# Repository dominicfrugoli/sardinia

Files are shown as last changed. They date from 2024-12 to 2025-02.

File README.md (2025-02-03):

<br/>
<div align="center">

<h3 align="center">Sardinia</h3>
<p align="center">
Sampler based on the Electrosmith Daisy platform

</p>
</div>

## About The Project

[Notion Project Homepage](https://fenidesign.notion.site/Sardinia-Independent-Project-24255e64caba44d3b6232d27743844be?pvs=4)

Sardinia is the codename for a sampler that is currently being built by me for an Independent Project during my senior year at Columbia College Chicago. It uses the Electrosmith Daisy platform and is an exercise for me to venture into the world of product design.

This independent project is called "The Product Design Process for Electronic Instruments" and was pitched by myself specifically to give myself experience in the process of the full production of an audio hardware device. This means starting at research, then going through every stage of production and design to end up with a final product. There is a large emphasis on the process and showing future companies that I understand somewhat what it takes.
### Built With

- [Daisy Seed](https://electro-smith.com/products/daisy-seed)
- [libDaisy](https://github.com/electro-smith/libDaisy)
- [DaisySP](https://github.com/electro-smith/DaisySP)
- [KiCad](https://www.kicad.org/)
- [Fusion 360](https://www.autodesk.com/products/fusion-360/)
## Roadmap

##### Weeks 1-5 | Ideation and Programming

- Week 1
    - Come up with overall idea and mission statement for the instrument
    - Research DSP ideas and programming concepts needed
    - Gather ideas and inspiration from specific hardware
- Week 2 & 3
    - Start programming all DSP and hardware handling for instrument
    - Lots of iteration and testing will be needed
    - Research here is critical as well to get main audio concepts down
    - Daisy Examples will be main research source
    - Recording different iterations of the project will be great for documentation
- Week 4 & 5
    - Work on finalizing code and getting it to a point for implementation
    - Use daisy examples and others’ code to help with style guidance
    - Get friends to test out for playability and sound, as well as get ideas
    - Build a central repo for code which can be updated as needed
    - Coding doesn’t stop with this step, but it should be mostly done by now
    - Start recording breadboard schematics if time allows to make PCB design easier

#####  Weeks 6-10 | PCB and Hardware Design

- Week 6 & 7
    - Refresh KICAD skills with tutorials
    - Build out schematic for PCB in KICAD
    - Design PCB completely and order for testing in week 8 & 9
    - Case design will be important here to make sure layout works with PCB
    - Final component selection will take place here
- Week 8 & 9
    - Work on case design with cardboard PCB to test out everything
    - Decide on case material (likely 3D printed)
    - Build out specifics for case such as standoff points and strength areas
    - Allow case to have daisy in a place that is easily reprogrammed
    - Assemble and test PCBs once they arrive (make changes and reorder if necessary)
    - Finish working on design and model for case
- Week 10
    - Start putting together first prototype of instrument with printed PCB and case
    - Play with instrument musically and have others try
    - This is when a lot of testing can be done for the usability

#####  Weeks 11-15 | Manufacturing and Documentation

- Week 11
    - Finalize design of case and overall visual style of instrument
    - Work on process for assembling, as well as BOM and any other assembly materials
- Week 12 & 13
    - Work on customer documentation for instrument
    - Design manual for the user
    - Design packaging for the instrument
    - Work on advertising and marketing for it
- Week 14 & 15
    - Build final version of instrument to be shown and displayed
        - Maybe one fully complete and two hollow cases for ad campaign
    - Final write up and documentation for instrument
    - Add writeup to portfolio website
    - Present it to friends and professors
    - Any last requirements for Visda

## Contact

Dominic Frugoli - [Portfolio](https://www.dominicfrugoli.com/) - dominicfrugoli@gmail.com

Project Link: [Notion Page](https://fenidesign.notion.site/Sardinia-Independent-Project-24255e64caba44d3b6232d27743844be?pvs=4)
## Acknowledgments

- Dr. Visda Goudarzi

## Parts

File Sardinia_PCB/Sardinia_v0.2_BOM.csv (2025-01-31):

Id | Designator | Footprint | Quantity | Designation | Supplier and ref
1 | R10,R24,R22,R31,R1,R17,R27,R21,R12,R19,R14,R3,R25,R9,R11,R7,R6,R18,R8,R26,R13,R30,R29,R15,R32,R23,R4,R16,R2,R5,R28,R20 | R_1206_3216Metric_Pad1.30x1.75mm_HandSolder | 32 | 10K
2 | RV3,RV1,RV6,RV5,RV4,RV2 | Potentiometer_Alpha_RD901F-40-00D_Single_Vertical | 6 | B10K
3 | SW34 | SW_Cherry_MX_1.00u_PCB | 1 | ControlButton_2
4 | SW14,SW10,SW3,SW30,SW24,SW16,SW5,SW1,SW9,SW23,SW31,SW32,SW26,SW15,SW17,SW13,SW7,SW19,SW22,SW20,SW28,SW25,SW18,SW4,SW29,SW27,SW8,SW12,SW2,SW21,SW6,SW11 | PG1350 | 32 | SW_Push
5 | RVT1 | Potentiometer_Runtron_RM-065_Vertical | 1 | B10K_Trim
6 | SW35 | SW_Cherry_MX_1.00u_PCB | 1 | ControlButton_3
7 | D1 | D_DO-41_SOD81_P7.62mm_Horizontal | 1 | 1N5817
8 | SW39 | SW_Cherry_MX_1.00u_PCB | 1 | ControlButton_7
9 | ENC1 | RotaryEncoder_Alps_EC11E-Switch_Vertical_H20mm | 1 | RotaryEncoder
10 | SW40 | SW_Cherry_MX_1.00u_PCB | 1 | ControlButton_8
11 | DS1 | WC1602A | 1 | LCD
12 | SW33 | SW_Cherry_MX_1.00u_PCB | 1 | ControlButton_1
13 | SW37 | SW_Cherry_MX_1.00u_PCB | 1 | ControlButton_5
14 | SW38 | SW_Cherry_MX_1.00u_PCB | 1 | ControlButton_6
15 | SW36 | SW_Cherry_MX_1.00u_PCB | 1 | ControlButton_4
16 | J3 | BarrelJack_Horizontal | 1 | DC Jack
17 | J2 | Jack_6.35mm_Neutrik_NMJ6HCD2_Horizontal | 1 | OutputJack
18 | J1 | Jack_6.35mm_Neutrik_NMJ6HCD2_Horizontal | 1 | InputJack
19 | C1 | CP_Radial_D5.0mm_P2.50mm | 1 | 10uF
20 | SW41 | JST_PH_B3B-PH-K_1x03_P2.00mm_Vertical | 1 | SW_SPDT
21 | U5,U4,U3,U2,U1 | DIP-16_W7.62mm_LongPads | 5 | 4051
22 | A1 | Electrosmith_Daisy_Seed | 1 | Electrosmith_Daisy_Seed_Rev4

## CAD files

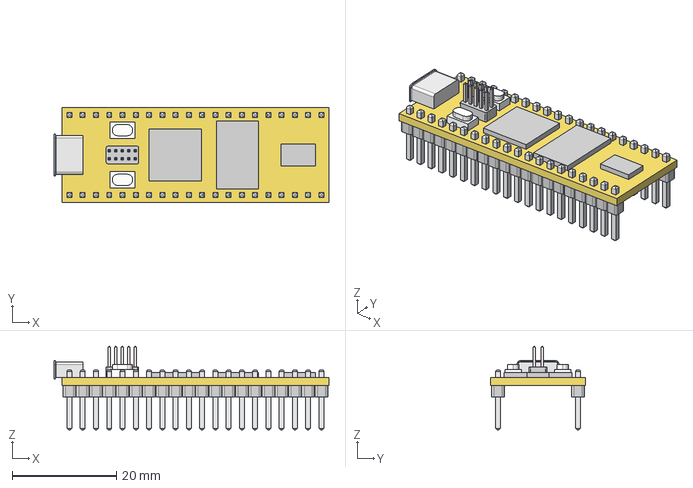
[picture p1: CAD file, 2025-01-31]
Sardinia_PCB/3Dmodels/Daisy Seed.step
52.7 x 18.1 x 16.0 mm

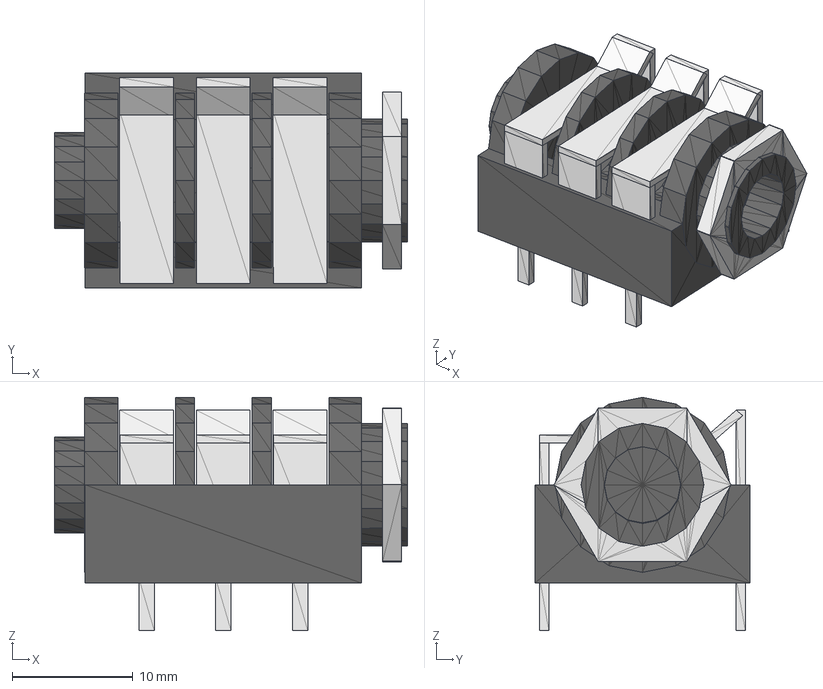
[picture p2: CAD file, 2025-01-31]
Sardinia_PCB/3Dmodels/NEUTRIKJKST.stp
29.2 x 17.8 x 19.3 mm
NEUTRIKJKST_2
NEUTRIKJKST_3
NEUTRIKJKST_4
NEUTRIKJKST_5
NEUTRIKJKST_6
NEUTRIKJKST_7
NEUTRIKJKST_8
NEUTRIKJKST_9
NEUTRIKJKST_10
NEUTRIKJKST_11
NEUTRIKJKST_12
NEUTRIKJKST_13
NEUTRIKJKST_14
NEUTRIKJKST_15
NEUTRIKJKST_16
NEUTRIKJKST_17
NEUTRIKJKST_18
NEUTRIKJKST_19
NEUTRIKJKST_20
NEUTRIKJKST_21
NEUTRIKJKST_22
NEUTRIKJKST_23
NEUTRIKJKST_24
NEUTRIKJKST_25
NEUTRIKJKST_26
NEUTRIKJKST_27
NEUTRIKJKST_28
NEUTRIKJKST_29
NEUTRIKJKST_30
NEUTRIKJKST_31
NEUTRIKJKST_32

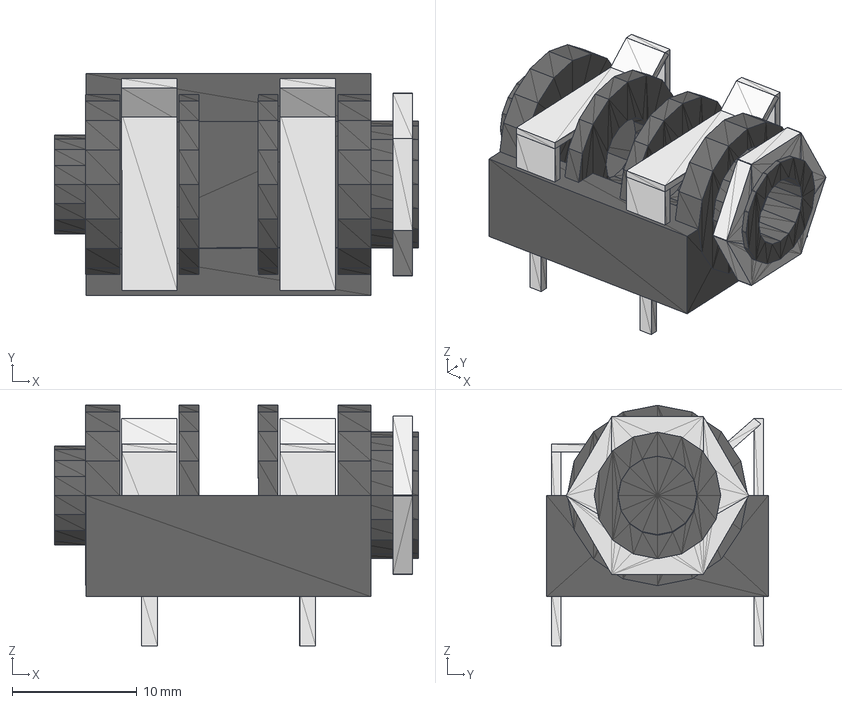
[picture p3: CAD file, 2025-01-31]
Sardinia_PCB/3Dmodels/NEUTRIKJK.stp
29.2 x 17.8 x 19.3 mm
NEUTRIKJK_2
NEUTRIKJK_3
NEUTRIKJK_4
NEUTRIKJK_5
NEUTRIKJK_6
NEUTRIKJK_7
NEUTRIKJK_8
NEUTRIKJK_9
NEUTRIKJK_10
NEUTRIKJK_11
NEUTRIKJK_12
NEUTRIKJK_13
NEUTRIKJK_14
NEUTRIKJK_15
NEUTRIKJK_16
NEUTRIKJK_17
NEUTRIKJK_18
NEUTRIKJK_19
NEUTRIKJK_20
NEUTRIKJK_21
NEUTRIKJK_22
NEUTRIKJK_23
NEUTRIKJK_24
NEUTRIKJK_25
NEUTRIKJK_26

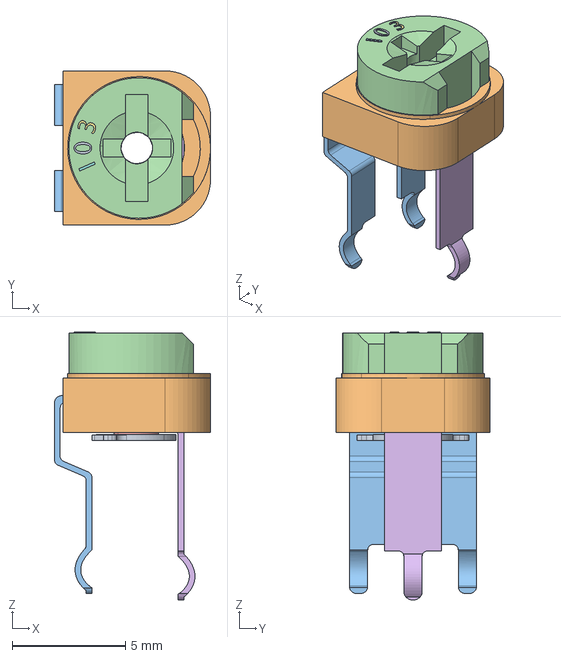
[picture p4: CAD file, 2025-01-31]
Sardinia_PCB/3Dmodels/Poti_10kohm.stp
6.88 x 6.80 x 11.8 mm

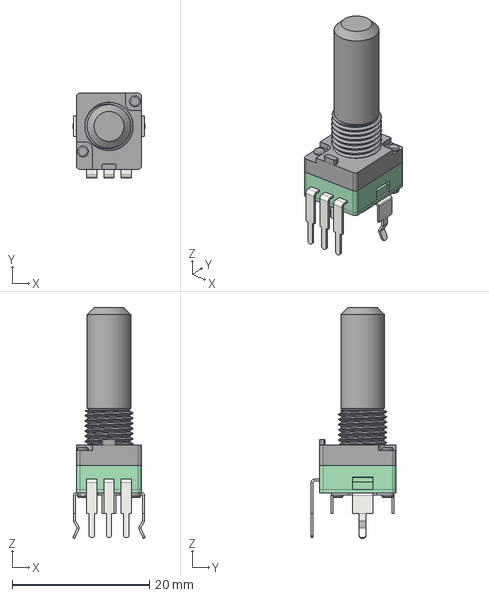
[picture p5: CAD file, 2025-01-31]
Sardinia_PCB/3Dmodels/ALPHA-RD901F-40.step
10.6 x 12.3 x 33.6 mm

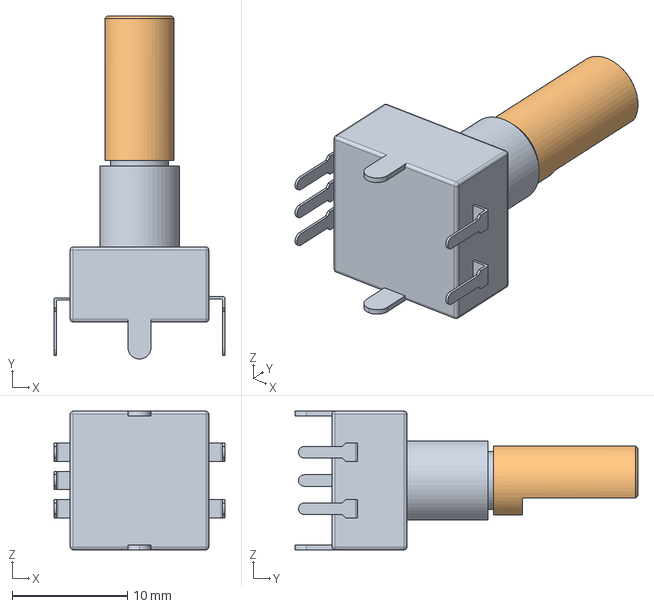
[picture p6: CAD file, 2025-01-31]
Sardinia_PCB/3Dmodels/Rotary_Encoder.step
14.8 x 29.7 x 12.0 mm

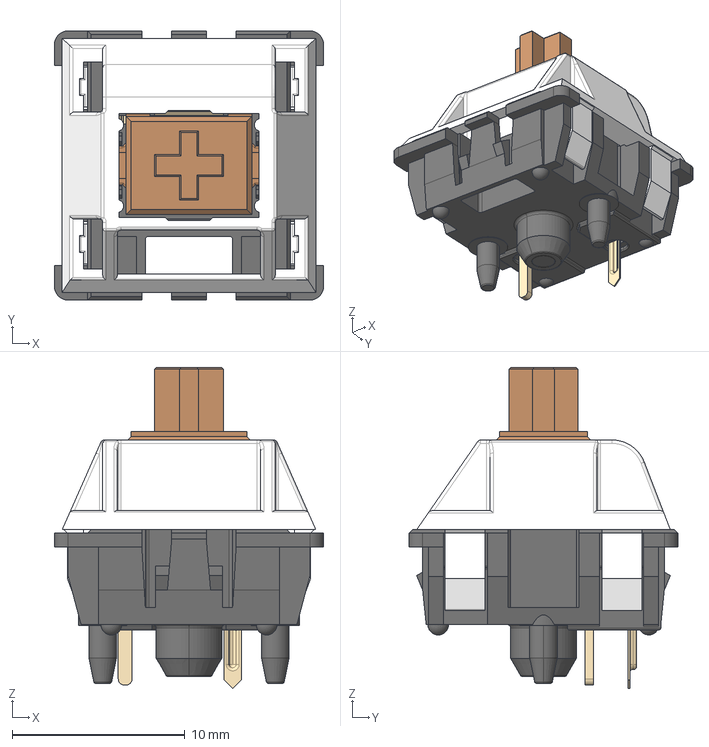
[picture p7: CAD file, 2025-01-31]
Sardinia_PCB/3Dmodels/SW_Cherry_MX_PCB.stp
15.6 x 15.6 x 18.6 mm

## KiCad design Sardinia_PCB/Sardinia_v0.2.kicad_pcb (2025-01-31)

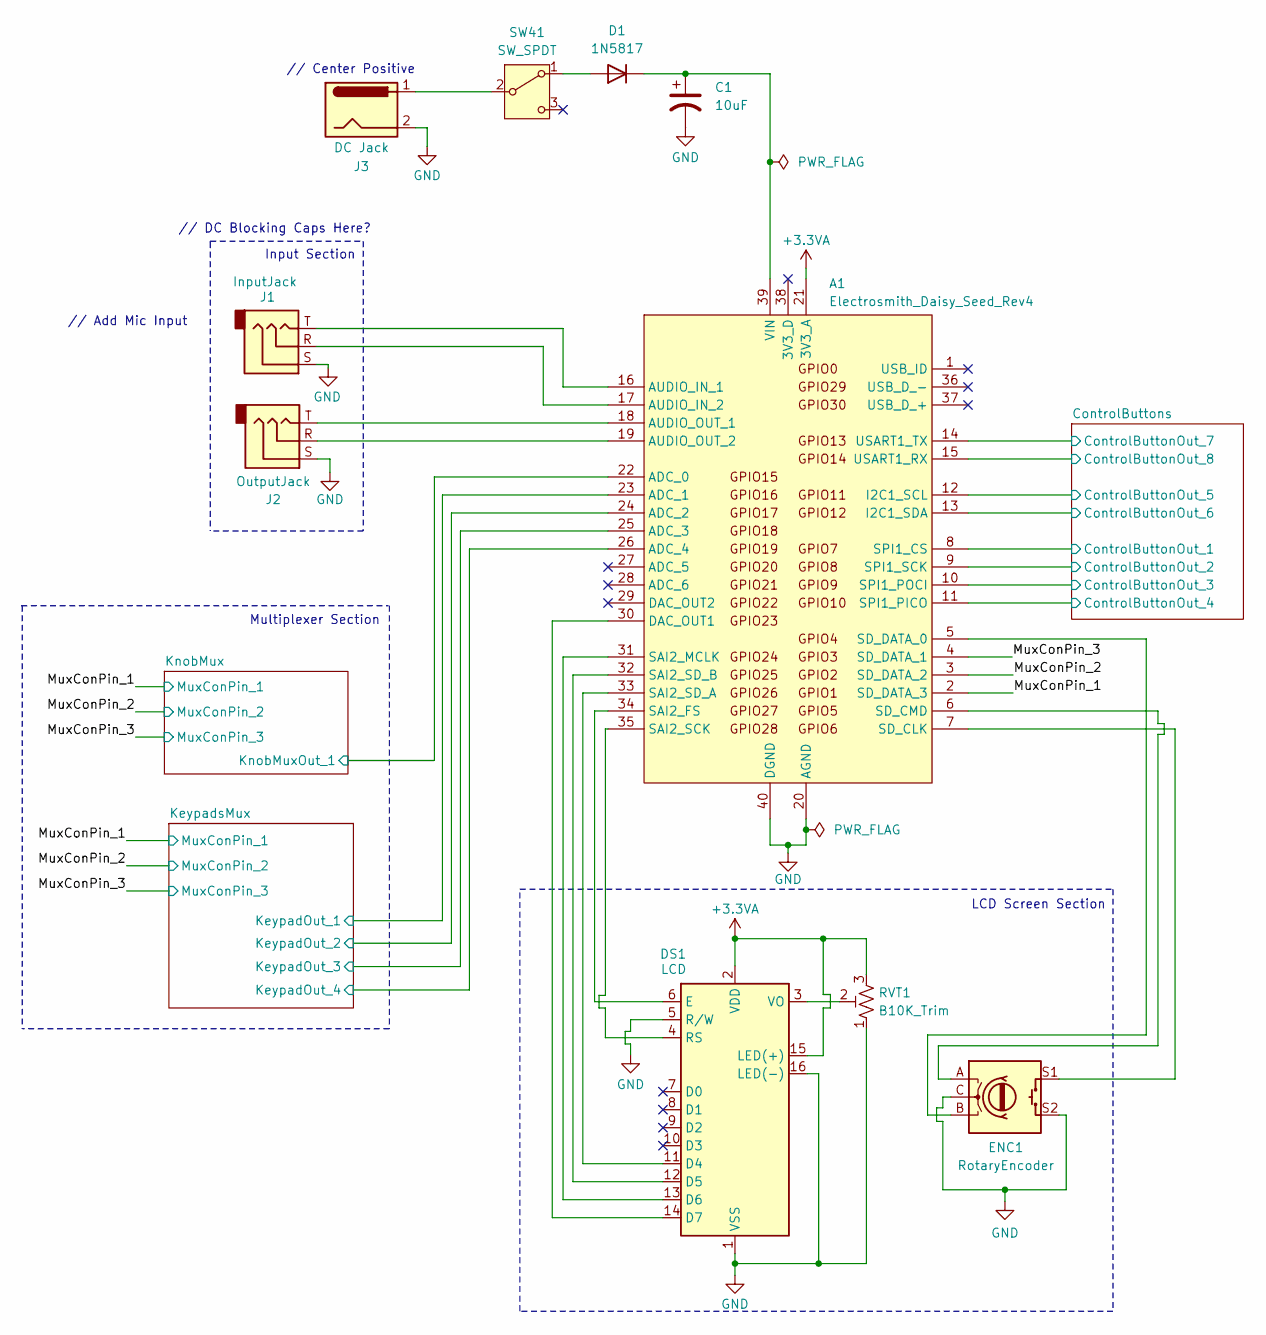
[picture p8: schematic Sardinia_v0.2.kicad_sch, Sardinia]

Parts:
A1: Electrosmith_Daisy_Seed_Rev4; Electrosmith_Daisy_Seed
C1: 10uF; CP_Radial_D5.0mm_P2.50mm
D1: 1N5817; D_DO-41_SOD81_P7.62mm_Horizontal
DS1: LCD; WC1602A
ENC1: RotaryEncoder; RotaryEncoder_Alps_EC11E-Switch_Vertical_H20mm
J1: InputJack; Jack_6.35mm_Neutrik_NMJ6HCD2_Horizontal
J2: OutputJack; Jack_6.35mm_Neutrik_NMJ6HCD2_Horizontal
J3: DC Jack; BarrelJack_Horizontal
RVT1: B10K_Trim; Potentiometer_Runtron_RM-065_Vertical
SW41: SW_SPDT; JST_PH_B3B-PH-K_1x03_P2.00mm_Vertical

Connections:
+3.3VA: A1.21 (3V3_A), DS1.2 (VDD), DS1.15 (LED(+)), RVT1.3; also elsewhere on the board
/ControlButtons/ControlButtonOut_1: A1.8 (SPI1_CS); also elsewhere on the board
/ControlButtons/ControlButtonOut_2: A1.9 (SPI1_SCK); also elsewhere on the board
/ControlButtons/ControlButtonOut_3: A1.10 (SPI1_POCI); also elsewhere on the board
/ControlButtons/ControlButtonOut_4: A1.11 (SPI1_PICO); also elsewhere on the board
/ControlButtons/ControlButtonOut_5: A1.12 (I2C1_SCL); also elsewhere on the board
/ControlButtons/ControlButtonOut_6: A1.13 (I2C1_SDA); also elsewhere on the board
/ControlButtons/ControlButtonOut_7: A1.14 (USART1_TX); also elsewhere on the board
/ControlButtons/ControlButtonOut_8: A1.15 (USART1_RX); also elsewhere on the board
/KeypadsMux/KeypadOut_1: A1.23 (ADC_1); also elsewhere on the board
/KeypadsMux/KeypadOut_2: A1.24 (ADC_2); also elsewhere on the board
/KeypadsMux/KeypadOut_3: A1.25 (ADC_3); also elsewhere on the board
/KeypadsMux/KeypadOut_4: A1.26 (ADC_4); also elsewhere on the board
/KnobMux/KnobMuxOut_1: A1.22 (ADC_0); also elsewhere on the board
/MuxConPin_1: A1.2 (SD_DATA_3); also elsewhere on the board
/MuxConPin_2: A1.3 (SD_DATA_2); also elsewhere on the board
/MuxConPin_3: A1.4 (SD_DATA_1); also elsewhere on the board
GND: A1.20 (AGND), A1.40 (DGND), C1.2, DS1.1 (VSS), DS1.5 (R/W), DS1.16 (LED(-)), ENC1.C, ENC1.S2, J1.S, J2.S, J3.2, RVT1.1; also elsewhere on the board
unnamed: A1.16 (AUDIO_IN_1), J1.T
unnamed: A1.17 (AUDIO_IN_2), J1.R
unnamed: A1.18 (AUDIO_OUT_1), J2.T
unnamed: A1.19 (AUDIO_OUT_2), J2.R
unnamed: A1.30 (DAC_OUT1), DS1.14 (D7)
unnamed: A1.34 (SAI2_FS), DS1.6 (E)
unnamed: A1.31 (SAI2_MCLK), DS1.13 (D6)
unnamed: A1.35 (SAI2_SCK), DS1.4 (RS)
unnamed: A1.33 (SAI2_SD_A), DS1.11 (D4)
unnamed: A1.32 (SAI2_SD_B), DS1.12 (D5)
unnamed: A1.7 (SD_CLK), ENC1.S1
unnamed: A1.6 (SD_CMD), ENC1.A
unnamed: A1.5 (SD_DATA_0), ENC1.B
unnamed: A1.39 (VIN), C1.1, D1.1 (K)
unnamed: D1.2 (A), SW41.1 (A)
unnamed: DS1.3 (VO), RVT1.2
unnamed: J3.1, SW41.2 (B)

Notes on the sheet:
// Center Positive
// Add Mic Input
LCD Screen Section
Input Section
// DC Blocking Caps Here?
Multiplexer Section

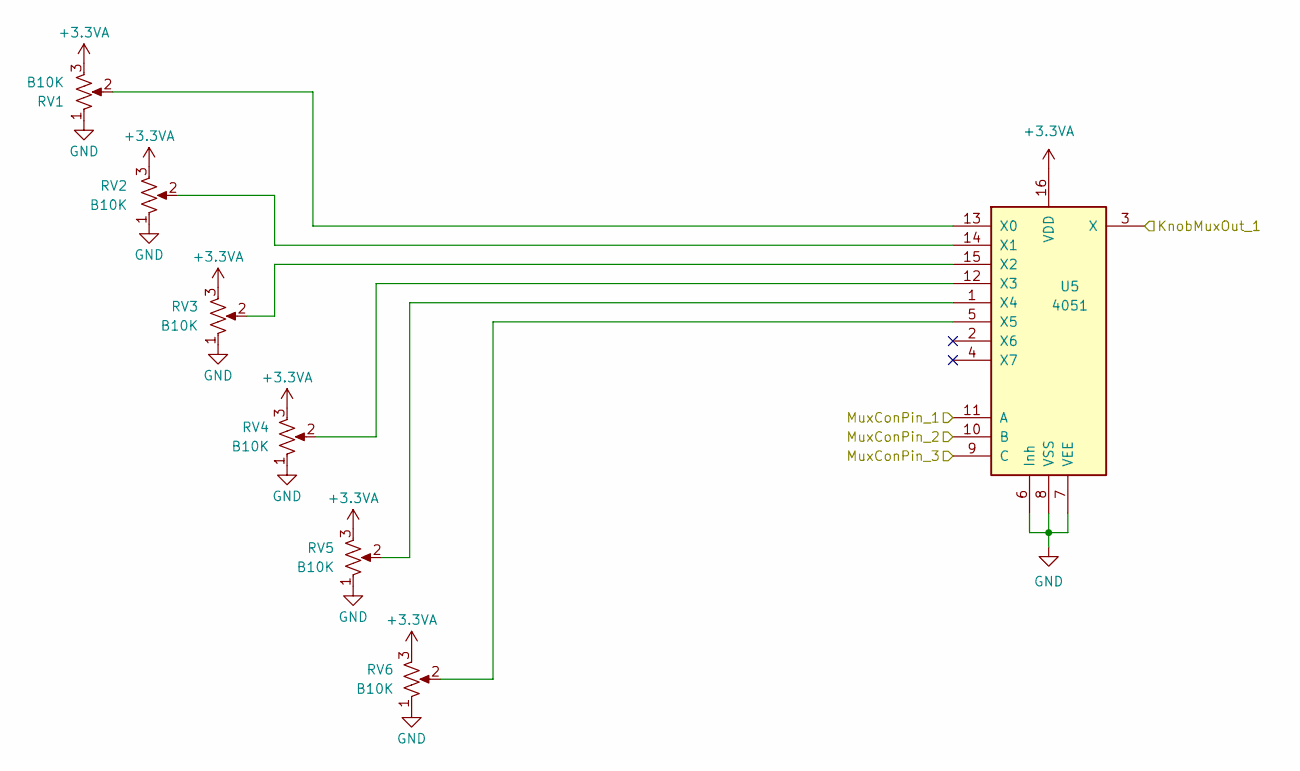
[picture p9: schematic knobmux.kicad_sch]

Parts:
RV1, RV2, RV3, RV4, RV5, RV6: B10K; Potentiometer_Alpha_RD901F-40-00D_Single_Vertical
U5: 4051; DIP-16_W7.62mm_LongPads

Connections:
+3.3VA: RV1.3, RV2.3, RV3.3, RV4.3, RV5.3, RV6.3, U5.16 (VDD); also elsewhere on the board
/KnobMux/KnobMuxOut_1: U5.3 (X); also elsewhere on the board
/MuxConPin_1: U5.11 (A); also elsewhere on the board
/MuxConPin_2: U5.10 (B); also elsewhere on the board
/MuxConPin_3: U5.9 (C); also elsewhere on the board
GND: RV1.1, RV2.1, RV3.1, RV4.1, RV5.1, RV6.1, U5.6 (Inh), U5.7 (VEE), U5.8 (VSS); also elsewhere on the board
unnamed: RV1.2, U5.13 (X0)
unnamed: RV2.2, U5.14 (X1)
unnamed: RV3.2, U5.15 (X2)
unnamed: RV4.2, U5.12 (X3)
unnamed: RV5.2, U5.1 (X4)
unnamed: RV6.2, U5.5 (X5)

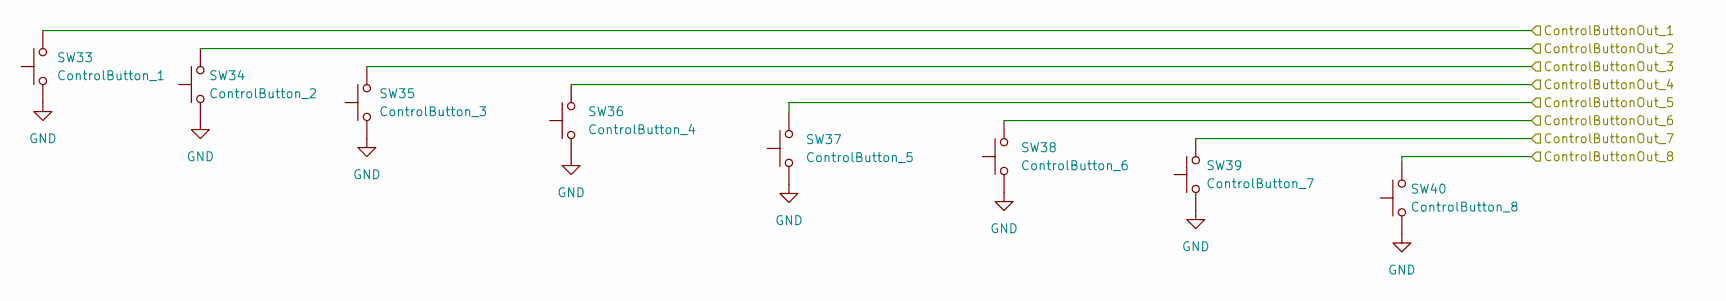
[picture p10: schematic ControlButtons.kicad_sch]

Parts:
SW33: ControlButton_1; SW_Cherry_MX_1.00u_PCB
SW34: ControlButton_2; SW_Cherry_MX_1.00u_PCB
SW35: ControlButton_3; SW_Cherry_MX_1.00u_PCB
SW36: ControlButton_4; SW_Cherry_MX_1.00u_PCB
SW37: ControlButton_5; SW_Cherry_MX_1.00u_PCB
SW38: ControlButton_6; SW_Cherry_MX_1.00u_PCB
SW39: ControlButton_7; SW_Cherry_MX_1.00u_PCB
SW40: ControlButton_8; SW_Cherry_MX_1.00u_PCB

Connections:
/ControlButtons/ControlButtonOut_1: SW33.2; also elsewhere on the board
/ControlButtons/ControlButtonOut_2: SW34.2; also elsewhere on the board
/ControlButtons/ControlButtonOut_3: SW35.2; also elsewhere on the board
/ControlButtons/ControlButtonOut_4: SW36.2; also elsewhere on the board
/ControlButtons/ControlButtonOut_5: SW37.2; also elsewhere on the board
/ControlButtons/ControlButtonOut_6: SW38.2; also elsewhere on the board
/ControlButtons/ControlButtonOut_7: SW39.2; also elsewhere on the board
/ControlButtons/ControlButtonOut_8: SW40.2; also elsewhere on the board
GND: SW33.1, SW34.1, SW35.1, SW36.1, SW37.1, SW38.1, SW39.1, SW40.1; also elsewhere on the board

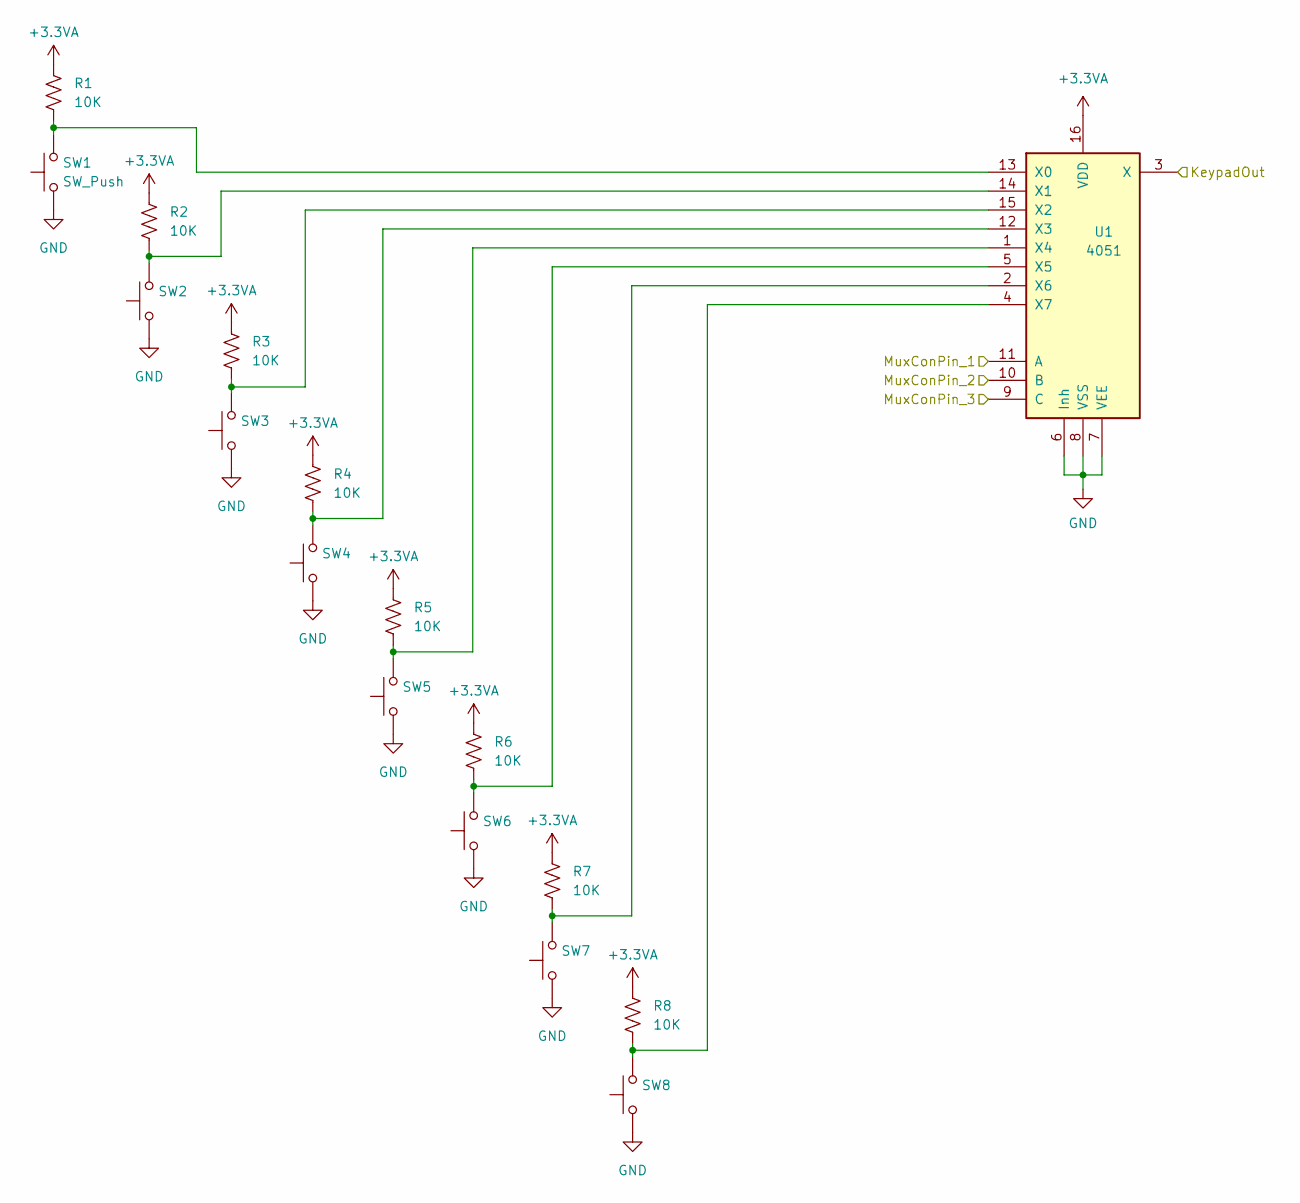
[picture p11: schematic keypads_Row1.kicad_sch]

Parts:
R1, R2, R3, R4, R5, R6, R7, R8: 10K; R_1206_3216Metric_Pad1.30x1.75mm_HandSolder
SW1, SW2, SW3, SW4, SW5, SW6, SW7, SW8: SW_Push; PG1350
U1: 4051; DIP-16_W7.62mm_LongPads

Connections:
+3.3VA: R1.1, R2.1, R3.1, R4.1, R5.1, R6.1, R7.1, R8.1, U1.16 (VDD); also elsewhere on the board
/KeypadsMux/KeypadOut_1: U1.3 (X); also elsewhere on the board
/MuxConPin_1: U1.11 (A); also elsewhere on the board
/MuxConPin_2: U1.10 (B); also elsewhere on the board
/MuxConPin_3: U1.9 (C); also elsewhere on the board
GND: SW1.1, SW2.1, SW3.1, SW4.1, SW5.1, SW6.1, SW7.1, SW8.1, U1.6 (Inh), U1.7 (VEE), U1.8 (VSS); also elsewhere on the board
unnamed: R1.2, SW1.2, U1.13 (X0)
unnamed: R2.2, SW2.2, U1.14 (X1)
unnamed: R3.2, SW3.2, U1.15 (X2)
unnamed: R4.2, SW4.2, U1.12 (X3)
unnamed: R5.2, SW5.2, U1.1 (X4)
unnamed: R6.2, SW6.2, U1.5 (X5)
unnamed: R7.2, SW7.2, U1.2 (X6)
unnamed: R8.2, SW8.2, U1.4 (X7)

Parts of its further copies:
R9, R10, R11, R12, R13, R14, R15, R16, R17, R18, R19, R20, R21, R22, R23, R24, R25, R26, R27, R28, R29, R30, R31, R32: 10K; R_1206_3216Metric_Pad1.30x1.75mm_HandSolder
SW9, SW10, SW11, SW12, SW13, SW14, SW15, SW16, SW17, SW18, SW19, SW20, SW21, SW22, SW23, SW24, SW25, SW26, SW27, SW28, SW29, SW30, SW31, SW32: SW_Push; PG1350
U2, U3, U4: 4051; DIP-16_W7.62mm_LongPads

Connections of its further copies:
+3.3VA: R9.1, R10.1, R11.1, R12.1, R13.1, R14.1, R15.1, R16.1, R17.1, R18.1, R19.1, R20.1, R21.1, R22.1, R23.1, R24.1, R25.1, R26.1, R27.1, R28.1, R29.1, R30.1, R31.1, R32.1, U2.16 (VDD), U3.16 (VDD), U4.16 (VDD); also elsewhere on the board
/KeypadsMux/KeypadOut_2: U2.3 (X); also elsewhere on the board
/KeypadsMux/KeypadOut_3: U3.3 (X); also elsewhere on the board
/KeypadsMux/KeypadOut_4: U4.3 (X); also elsewhere on the board
/MuxConPin_1: U2.11 (A), U3.11 (A), U4.11 (A); also elsewhere on the board
/MuxConPin_2: U2.10 (B), U3.10 (B), U4.10 (B); also elsewhere on the board
/MuxConPin_3: U2.9 (C), U3.9 (C), U4.9 (C); also elsewhere on the board
GND: SW9.1, SW10.1, SW11.1, SW12.1, SW13.1, SW14.1, SW15.1, SW16.1, SW17.1, SW18.1, SW19.1, SW20.1, SW21.1, SW22.1, SW23.1, SW24.1, SW25.1, SW26.1, SW27.1, SW28.1, SW29.1, SW30.1, SW31.1, SW32.1, U2.6 (Inh), U2.7 (VEE), U2.8 (VSS), U3.6 (Inh), U3.7 (VEE), U3.8 (VSS), U4.6 (Inh), U4.7 (VEE), U4.8 (VSS); also elsewhere on the board
unnamed: R9.2, SW9.2, U2.13 (X0)
unnamed: R10.2, SW10.2, U2.14 (X1)
unnamed: R11.2, SW11.2, U2.15 (X2)
unnamed: R12.2, SW12.2, U2.12 (X3)
unnamed: R13.2, SW13.2, U2.1 (X4)
unnamed: R14.2, SW14.2, U2.5 (X5)
unnamed: R15.2, SW15.2, U2.2 (X6)
unnamed: R16.2, SW16.2, U2.4 (X7)
unnamed: R17.2, SW17.2, U3.13 (X0)
unnamed: R18.2, SW18.2, U3.14 (X1)
unnamed: R19.2, SW19.2, U3.15 (X2)
unnamed: R20.2, SW20.2, U3.12 (X3)
unnamed: R21.2, SW21.2, U3.1 (X4)
unnamed: R22.2, SW22.2, U3.5 (X5)
unnamed: R23.2, SW23.2, U3.2 (X6)
unnamed: R24.2, SW24.2, U3.4 (X7)
unnamed: R25.2, SW25.2, U4.13 (X0)
unnamed: R26.2, SW26.2, U4.14 (X1)
unnamed: R27.2, SW27.2, U4.15 (X2)
unnamed: R28.2, SW28.2, U4.12 (X3)
unnamed: R29.2, SW29.2, U4.1 (X4)
unnamed: R30.2, SW30.2, U4.5 (X5)
unnamed: R31.2, SW31.2, U4.2 (X6)
unnamed: R32.2, SW32.2, U4.4 (X7)

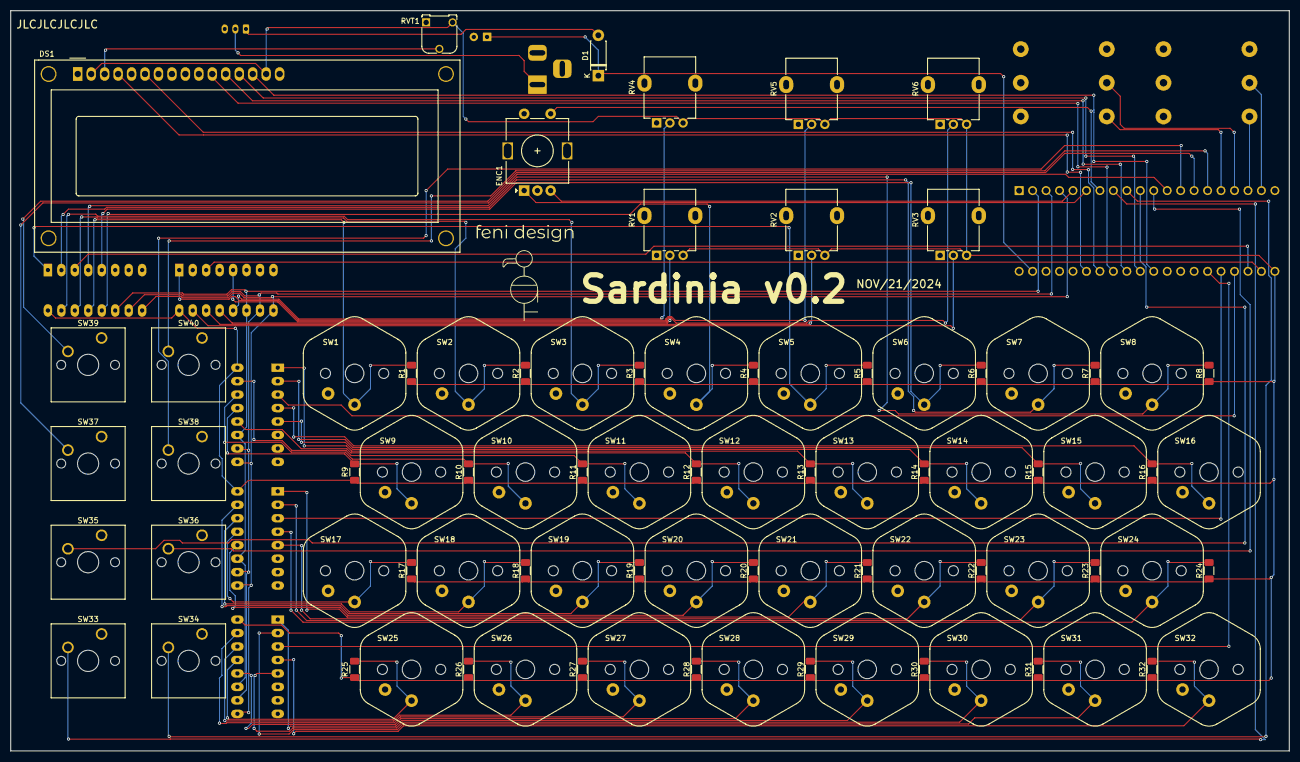
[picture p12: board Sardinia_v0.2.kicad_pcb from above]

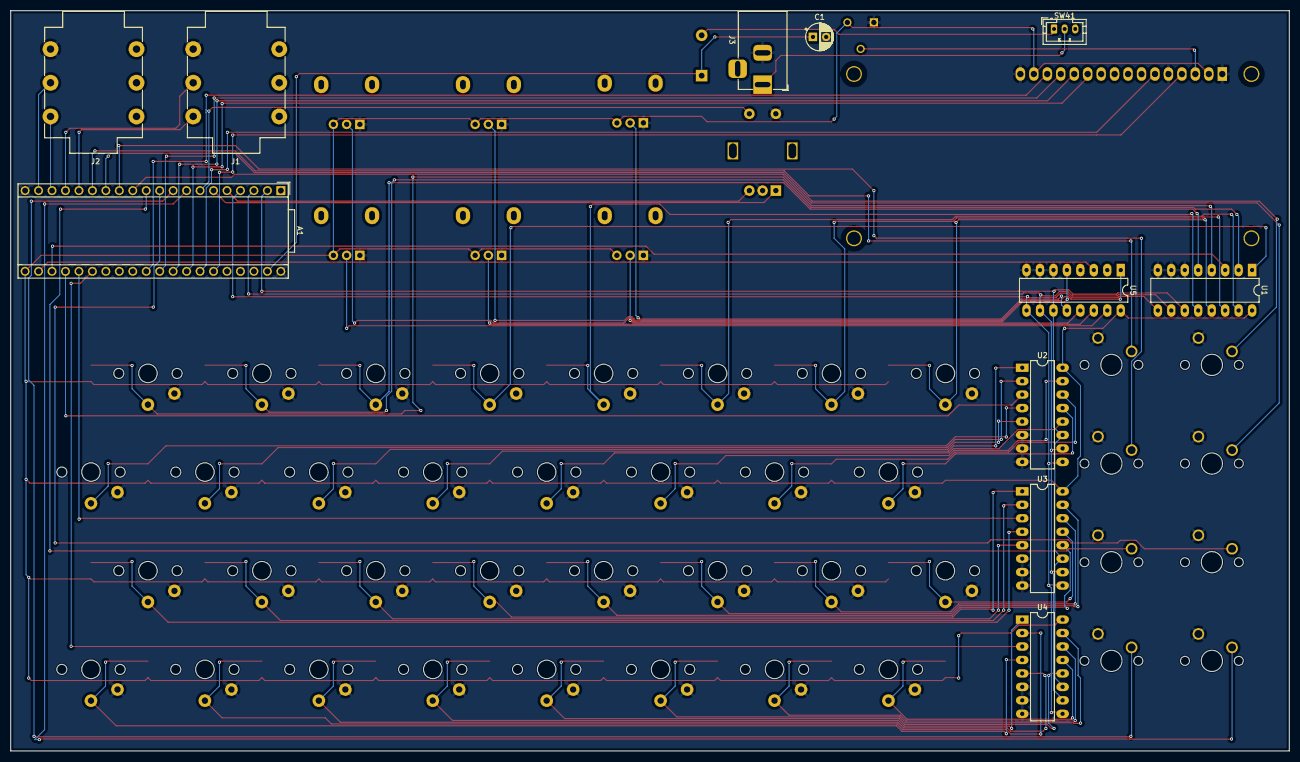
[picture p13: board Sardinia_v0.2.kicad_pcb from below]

Board: 4 copper layers, 241.3 x 139.7 mm, 93 parts (11 on the bottom side), 73 nets.

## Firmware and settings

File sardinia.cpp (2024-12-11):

// ================================
// COMPANY: Feni Design
// AUTHOR: Dominic Frugoli
// CREATE DATE: 8/18/2024
// PROJECT: Fall 2024 Independent Project
// HEADER FILES NEEDED: "hardware.h"
// SPECIAL NOTES: Code is meant for Electrosmith Daisy microcontroller
// ================================


// |Includes and Namespaces|------------------------------------------------------------------------------------------


#include "daisy_seed.h"
#include "daisysp.h"
#include "hardware.h"
#include "sampleengine.h"
#include "display.h"
#include "effects.h"

using namespace daisy;
using namespace daisy::seed;
using namespace daisysp;


// |Hardware Instantiations|------------------------------------------------------------------------------------------


DaisySeed hw;


// |Audio Objects + Variables|------------------------------------------------------------------------------------------


float outputMix;
float sampleSig;
float inputSig;
float outputAmp = 0.5f;
float inputAmp = 1.0f;



void ProcessControlsKR();
void ProcessControlsAR();
void RecordModeControls();
void PlayModeControls();
void UpdateKeys();
void UpdateControlButtons();
void ModeSelect();
void PrintMenu();


// |Main Setup and Audio Callback|------------------------------------------------------------------------------------------


void AudioCallback(AudioHandle::InputBuffer in, AudioHandle::OutputBuffer out, size_t size) 
{
	ProcessControlsKR();

	for (size_t i = 0; i < size; i++)
	{
		sampleSig = 0; // Reset signal values to 0 in case no sample is being played
		outputMix = 0;

		ProcessControlsAR();

		inputSig = (in[0][i] + in[1][i]) * 0.5f; 
		inputSig *= inputAmp;
		
		if(isRecording)
		{
			RecordSample((inputSig)); // Record the input and increment the sample length tracker
			lengthTrack++;
		}

		if(isPlaying && AnyKeyIsPressed() == false) // If no keys are pressed, play the full sample
		{
			sampleSig = FullSampleGetSample();
		}
		else if(SpliceBufferIsPlaying)
		{
			sampleSig = SpliceBufferGetSample(currentSpliceBuffer, mode, noteKey);
		}
		else if(isPlaying)
		{
			sampleSig = GetSample();
			AdvanceReadIndex();
			if(readIndex > recordingLength) // recordingLength dynamically changes the size of sample based on recording
			{
				readIndex = 0;
			}
		}

		
		outputMix = inputSig + sampleSig; // Mix the sample playback with the input
		outputMix = ProcessEffects(outputMix); // Process the mixed signal through the effects
		outputMix *= outputAmp;

		// Output the mixed signals
        out[0][i] = outputMix;
		out[1][i] = outputMix;
	}
}

int main(void)
{
	hw.Init();
	hw.SetAudioBlockSize(4); // number of samples handled per callback
	hw.SetAudioSampleRate(SaiHandle::Config::SampleRate::SAI_48KHZ);
	float sampleRate = hw.AudioSampleRate();

	InitLCD();
	InitControls();
	hw.adc.Init(adcConfig, NUM_ADC_CHANNELS); //initializes adc system using the config and number of channels
	hw.adc.Start();
	
	InitBuffer(); // Initialize buffer to all 0s
	InitEffects(sampleRate);

	//hw.StartLog(true); // Use for serial testing. COMMENT OUT WHEN NOT USING!!

	hw.StartAudio(AudioCallback);

	while(1)
	{
		PrintMenu(currentEffect, effectStates);
		//hw.PrintLine("Print a float value: %f", recordingLength);
		System::Delay(50);
	}
}


// |Offboard Control Functions|------------------------------------------------------------------------------------------


void ProcessControlsKR() // For controls that only need to be processed every audio block
{
	UpdateKeys();	

	encoder.Debounce();

	if(EncoderTurned())
	{
		IncrementEffect(encoder.Increment());
	}
	if(encoder.RisingEdge())
	{
		effectStates[currentEffect] = !effectStates[currentEffect];
	}

	if(currentEffect == 0)
	{
		effectValues[0][0] = fmap(hw.adc.GetMuxFloat(0, 1), 0, 1, Mapping::LINEAR); // Overdrive Gain
		effectValues[0][1] = fmap(hw.adc.GetMuxFloat(0, 4), .01, .3, Mapping::EXP); // Overdrive Tone Freq
	}
	else if(currentEffect == 1)
	{
		effectValues[1][0] = fmap(hw.adc.GetMuxFloat(0, 1), 0, 1, Mapping::LINEAR); // Chorus LFO Depth
		effectValues[1][1] = fmap(hw.adc.GetMuxFloat(0, 4), 0, 10, Mapping::EXP); // Chorus LFO Freq
	}
	else if(currentEffect == 2)
	{
		effectValues[2][0] = fmap(hw.adc.GetMuxFloat(0, 1), 0, 5000, Mapping::EXP); // LoPass Freq
		effectValues[2][1] = fmap(hw.adc.GetMuxFloat(0, 4), 0, 1, Mapping::LINEAR); // LoPass Res
	}
	

	outputAmp = fmap(hw.adc.GetMuxFloat(0, 2), 0, 2, Mapping::LINEAR); // top far right
	inputAmp = fmap(hw.adc.GetMuxFloat(0, 5), 0, 2, Mapping::LINEAR); // bottom far right
	
	readFactor = fmap(hw.adc.GetMuxFloat(0, 3), 0.5, 2, Mapping::EXP); // top far left


	ProcessEffectParameters();
}

void ProcessControlsAR() // For controls that need to process every sample
{
	// All control keys must be updated at same clock cycle 
	// So all control key functions must be done at audio rate
	UpdateControlButtons(); 
	ModeSelect();

	if(controlButtons[0].RisingEdge()) // Starts the sample from the beginning when pressed
	{
		if(isPlaying == false)
		{
			fullSampleReadIndex = 0;
			isPlaying = true;
			playButtonOverrule = true;
		}
		else
		{
			isPlaying = false;
			playButtonOverrule = false;
		}
	}
	else if(fullSampleReadIndex== 0 && !controlButtons[0].Pressed()) // Stops the sample when let go
	{
		isPlaying = false;
		playButtonOverrule = false;
	}
	
	if(mode == record)
	{
		RecordModeControls();
	}
	else if(mode == play)
	{
		PlayModeControls();
	}
}

void RecordModeControls() // Controls that only run in record mode
{	

	// Recording
	if(controlButtons[1].RisingEdge()) // Starts recording from start on press and resets the length track
	{
		isRecording = true;
		testValFloat = 1;
		lengthTrack = 0;
	}
	else if(controlButtons[1].FallingEdge()) // Stops recording when let go, resets write index, and assigns recording length
	{
		isRecording = false;
		writeIndex = 0;
		recordingLength = lengthTrack;
		testValFloat = 0;
		testValInt = recordingLength;
		SetKeyIndexs();
	}

	// Play slices from keypads
	if(playButtonOverrule == false)
	{
		if(AnyKeyIsPressed())
		{
			isPlaying = true;
		}
		else
		{
			isPlaying = false;
		}
	}

	// Store Splices into Buffers
	if(controlButtons[4].RisingEdge())
	{
		currentSpliceBuffer = 1;
		if(AnyKeyIsPressed())
		{
			StoreSpliceBuffer(currentSpliceBuffer);
		}
	}
	if(controlButtons[5].RisingEdge())
	{
		currentSpliceBuffer = 2;
		if(AnyKeyIsPressed())
		{
			StoreSpliceBuffer(currentSpliceBuffer);
		}
	}
	if(controlButtons[6].RisingEdge())
	{
		currentSpliceBuffer = 3;
		if(AnyKeyIsPressed())
		{
			StoreSpliceBuffer(currentSpliceBuffer);
		}
	}
	if(controlButtons[7].RisingEdge())
	{
		currentSpliceBuffer = 4;
		if(AnyKeyIsPressed())
		{
			StoreSpliceBuffer(currentSpliceBuffer);
		}
	}
}

void PlayModeControls()
{
	// Play splices on keypads
	if(playButtonOverrule == false)
	{
		if(AnyKeyIsPressed())
		{
			SpliceBufferIsPlaying = true;
		}
		else
		{
			SpliceBufferIsPlaying = false;
		}
	}

	// Switch current buffer to play
	if(controlButtons[4].RisingEdge())
	{
		currentSpliceBuffer = 1;
	}
	if(controlButtons[5].RisingEdge())
	{
		currentSpliceBuffer = 2;
	}
	if(controlButtons[6].RisingEdge())
	{
		currentSpliceBuffer = 3;
	}
	if(controlButtons[7].RisingEdge())
	{
		currentSpliceBuffer = 4;
	}

}

void UpdateKeys()
{
	for(int i = 0; i < 8; i++)
	{
		keyStates[i] = hw.adc.GetMuxFloat(1, i) < 0.5f;
	}
	for(int i = 8; i < 16; i++)
	{
		keyStates[i] = hw.adc.GetMuxFloat(2, i - 8) < 0.5f;
	}
	for(int i = 16; i < 24; i++)
	{
		keyStates[i] = hw.adc.GetMuxFloat(3, i - 16) < 0.5f;
	}
	for(int i = 24; i < 32; i++)
	{
		keyStates[i] = hw.adc.GetMuxFloat(4, i - 24) < 0.5f;
	}
	noteKey = FindFirstPressedKey();
}


void ModeSelect()
{
	if(controlButtons[2].RisingEdge()) // Adjusts the output amplitude based on the knob
	{
		UpdateMode(0);
	}
	else if(controlButtons[3].RisingEdge()) // Adjusts the input amplitude based on the knob
	{
		UpdateMode(1);
	}
}

void UpdateControlButtons()
{
	for(int i = 0; i < 8; i++)
	{
		controlButtons[i].Debounce();
	}
}




// |Audio Object Init Functions|------------------------------------------------------------------------------------------

	// Most of these are now in sampleengine.h

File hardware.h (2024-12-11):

// ================================
// COMPANY: Feni Design
// AUTHOR: Dominic Frugoli
// CREATE DATE: 8/25/2024
// PROJECT: Fall 2024 Independent Project
// HEADER FILE FOR USE WITH: "sardinia.cpp"
// SPECIAL NOTES: Code is meant for Electrosmith Daisy microcontroller
// ================================


using namespace daisy;
using namespace daisy::seed;


// |Pin Declarations|------------------------------------------------------------------------------------------
// Setting up pin locations for all hardware

#define numKeyPads 32

#define knobMuxPin A0
#define keypadMuxPin_Row1 A1
#define keypadMuxPin_Row2 A2
#define keypadMuxPin_Row3 A3
#define keypadMuxPin_Row4 A4

#define muxConPin1 D1
#define muxConPin2 D2
#define muxConPin3 D3

#define encoderPinB D4
#define encoderPinA D5
#define encoderPinClick D6 

#define controlButtonPin_One D7
#define controlButtonPin_Two D8
#define controlButtonPin_Three D9
#define controlButtonPin_Four D10
#define controlButtonPin_Five D11
#define controlButtonPin_Six D12
#define controlButtonPin_Seven D13
#define controlButtonPin_Eight D14

Pin controlButtonPins[8] = {controlButtonPin_One, controlButtonPin_Two, controlButtonPin_Three, controlButtonPin_Four, controlButtonPin_Five, controlButtonPin_Six, controlButtonPin_Seven, controlButtonPin_Eight};



// |ADC Config Setup|------------------------------------------------------------------------------------------
// Setting up ADC system for Daisy

enum AdcChannel // Just add knobs before last NUM_ADC_CHANNELS as needed
{
	knobMux,
	keypadMuxOne,
	keypadMuxTwo,
	keypadMuxThree,
	keypadMuxFour,
	NUM_ADC_CHANNELS // Enum allows for auto tracking the amount
};


// |Hardware Object Instantiations|------------------------------------------------------------------------------------------
// Instantiating objects for hardware control classes


AdcChannelConfig adcConfig[NUM_ADC_CHANNELS]; // array size for number of ADC channels you need

Switch controlButtons[8];

Encoder encoder;


// |Variable Declarations|------------------------------------------------------------------------------------------
// Variables for all values that need to be stored


int encoderTurnVal;

// 0: play, 1: record, 2: ???, 3: ???, 4: ModeOne, 5: ModeTwo, 6: ModeThree, 7: ModeFour
bool controlButtonStates[8] = {false, false, false, false, false, false, false, false};
bool prevControlButtonStates[8] = {false, false, false, false, false, false, false, false};

bool playButtonOverrule; // For when the playing sample off of play button pressed (overrules keypad)


// |Function Declarations|------------------------------------------------------------------------------------------
// Function declarations for any functions needed

void ProcessControlsKR(); // For controls that only need to be processed every audio block
void ProcessControlsAR(); // For controls that need to process every sample

void InitControls()
{
	adcConfig[knobMux].InitMux(knobMuxPin, 8, muxConPin1, muxConPin2, muxConPin3);
	adcConfig[keypadMuxOne].InitMux(keypadMuxPin_Row1, 8, muxConPin1, muxConPin2, muxConPin3);
	adcConfig[keypadMuxTwo].InitMux(keypadMuxPin_Row2, 8, muxConPin1, muxConPin2, muxConPin3);
	adcConfig[keypadMuxThree].InitMux(keypadMuxPin_Row3, 8, muxConPin1, muxConPin2, muxConPin3);
	adcConfig[keypadMuxFour].InitMux(keypadMuxPin_Row4, 8, muxConPin1, muxConPin2, muxConPin3);

	for(int i = 0; i < 8; i++)
	{
		controlButtons[i].Init(controlButtonPins[i], 1000);
	}

	encoder.Init(encoderPinA, encoderPinB, encoderPinClick);
}

bool RisingEdge(bool buttonState, bool previousButtonState)
{
	if(buttonState == true && previousButtonState == false)
	{
		return true;
	}
	else
	{
		return false;
	}
}

bool FallingEdge(bool buttonState, bool previousButtonState)
{
	if(buttonState == false && previousButtonState == true)
	{
		return true;
	}
	else
	{
		return false;
	}
}

bool EncoderTurned()
{
	float encoderInc = encoder.Increment();
	if(encoderInc != 0)
	{
		return true;
	}
	else
	{
		return false;
	}
}

bool EncoderTurned(Encoder enc)
{
	float encoderInc = enc.Increment();
	if(encoderInc != 0)
	{
		encoderInc = 0;
		return true;
	}
	else
	{
		encoderInc = 0;
		return false;
	}
}

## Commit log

2024-10-23 PCB hardware and sampler work
    Updated all the hardware handling to fit with the prototype PCB and implemented some parts of the sampler algorithm (not working yet)
    [display.h, hardware.h, sampleengine.h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]
2024-11-07 Eliminated play and record buttons (legacy code)
2024-12-11 Changed Control Buttons Code
    Control Buttons on new PCB don't go through a MUX. They go directly to the MCU so I removed the code that manually checked for rising edge/falling edge. I used the built in Switch class for it instea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
2025-01-31 Added KiCad files
    [ALPHA-RD901F-40.step, ButtonsMux.kicad_sch, ControlButtons.kicad_sch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]
